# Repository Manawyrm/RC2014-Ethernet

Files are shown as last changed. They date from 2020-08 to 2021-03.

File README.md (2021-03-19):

RC2014 RTL8019 Ethernet card
---------------------

RTL8019 network card  

The design is optimized for automated assembly at [JLCPCB](https://jlcpcb.com/DDE).  

[Schematic](gerbers/RevA/RevA.pdf)  
[Firmware](https://github.com/Manawyrm/RC2014-Ethernet-Firmware)  

Rev. A Errata:   
- Reset polarity is wrong, reset trace needs to be cut and wired to VCC (reset is done in software)
- Interrupt polarity is also wrong, remove R7. (to use interrupts, use an N-channel MOSFET to drive the INT line. Untested!)
- RTL8019 requires an SPI 9346 EEPROM for it's configuration data (for full-duplex ethernet, correct function of the LEDs, proper MAC addresses), which is missing
- RTL8019 footprint is wrong (too small). JLCPCB can still assemble these boards, but it's marked as a manufacturing error.

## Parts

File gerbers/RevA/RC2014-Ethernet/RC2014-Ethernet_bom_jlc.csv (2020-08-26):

Comment | Designator | Footprint | LCSC Part #
1nF | C2,C1,C5,C6 | C_1206_3216Metric | C9196
20p | C3,C4 | C_0402_1005Metric | C1554
100n | C7,C9,C10,C8,C11 | C_0402_1005Metric | C1525
Ferrite_Bead | FB3 | L_0805_2012Metric | C1017
27k | R1 | R_0402_1005Metric | C25771
1M | R2 | R_0402_1005Metric | C26083
10k | R3 | R_0402_1005Metric | C25744
200R | R4,R7 | R_0402_1005Metric | C25087
1k | R5,R6 | R_0402_1005Metric | C11702
13F-39MNL | T1 | SOIC-16W-12_7.5x10.3mm_P1.27mm | C115949
RTL8019AS | U1 | PQFP-100_14x20mm_P0.65mm | C10016
74LS138 | U2 | SOIC-16_3.9x9.9mm_P1.27mm | C5602
20MHz | Y1 | Crystal_SMD_3225-4Pin_3.2x2.5mm | C110936

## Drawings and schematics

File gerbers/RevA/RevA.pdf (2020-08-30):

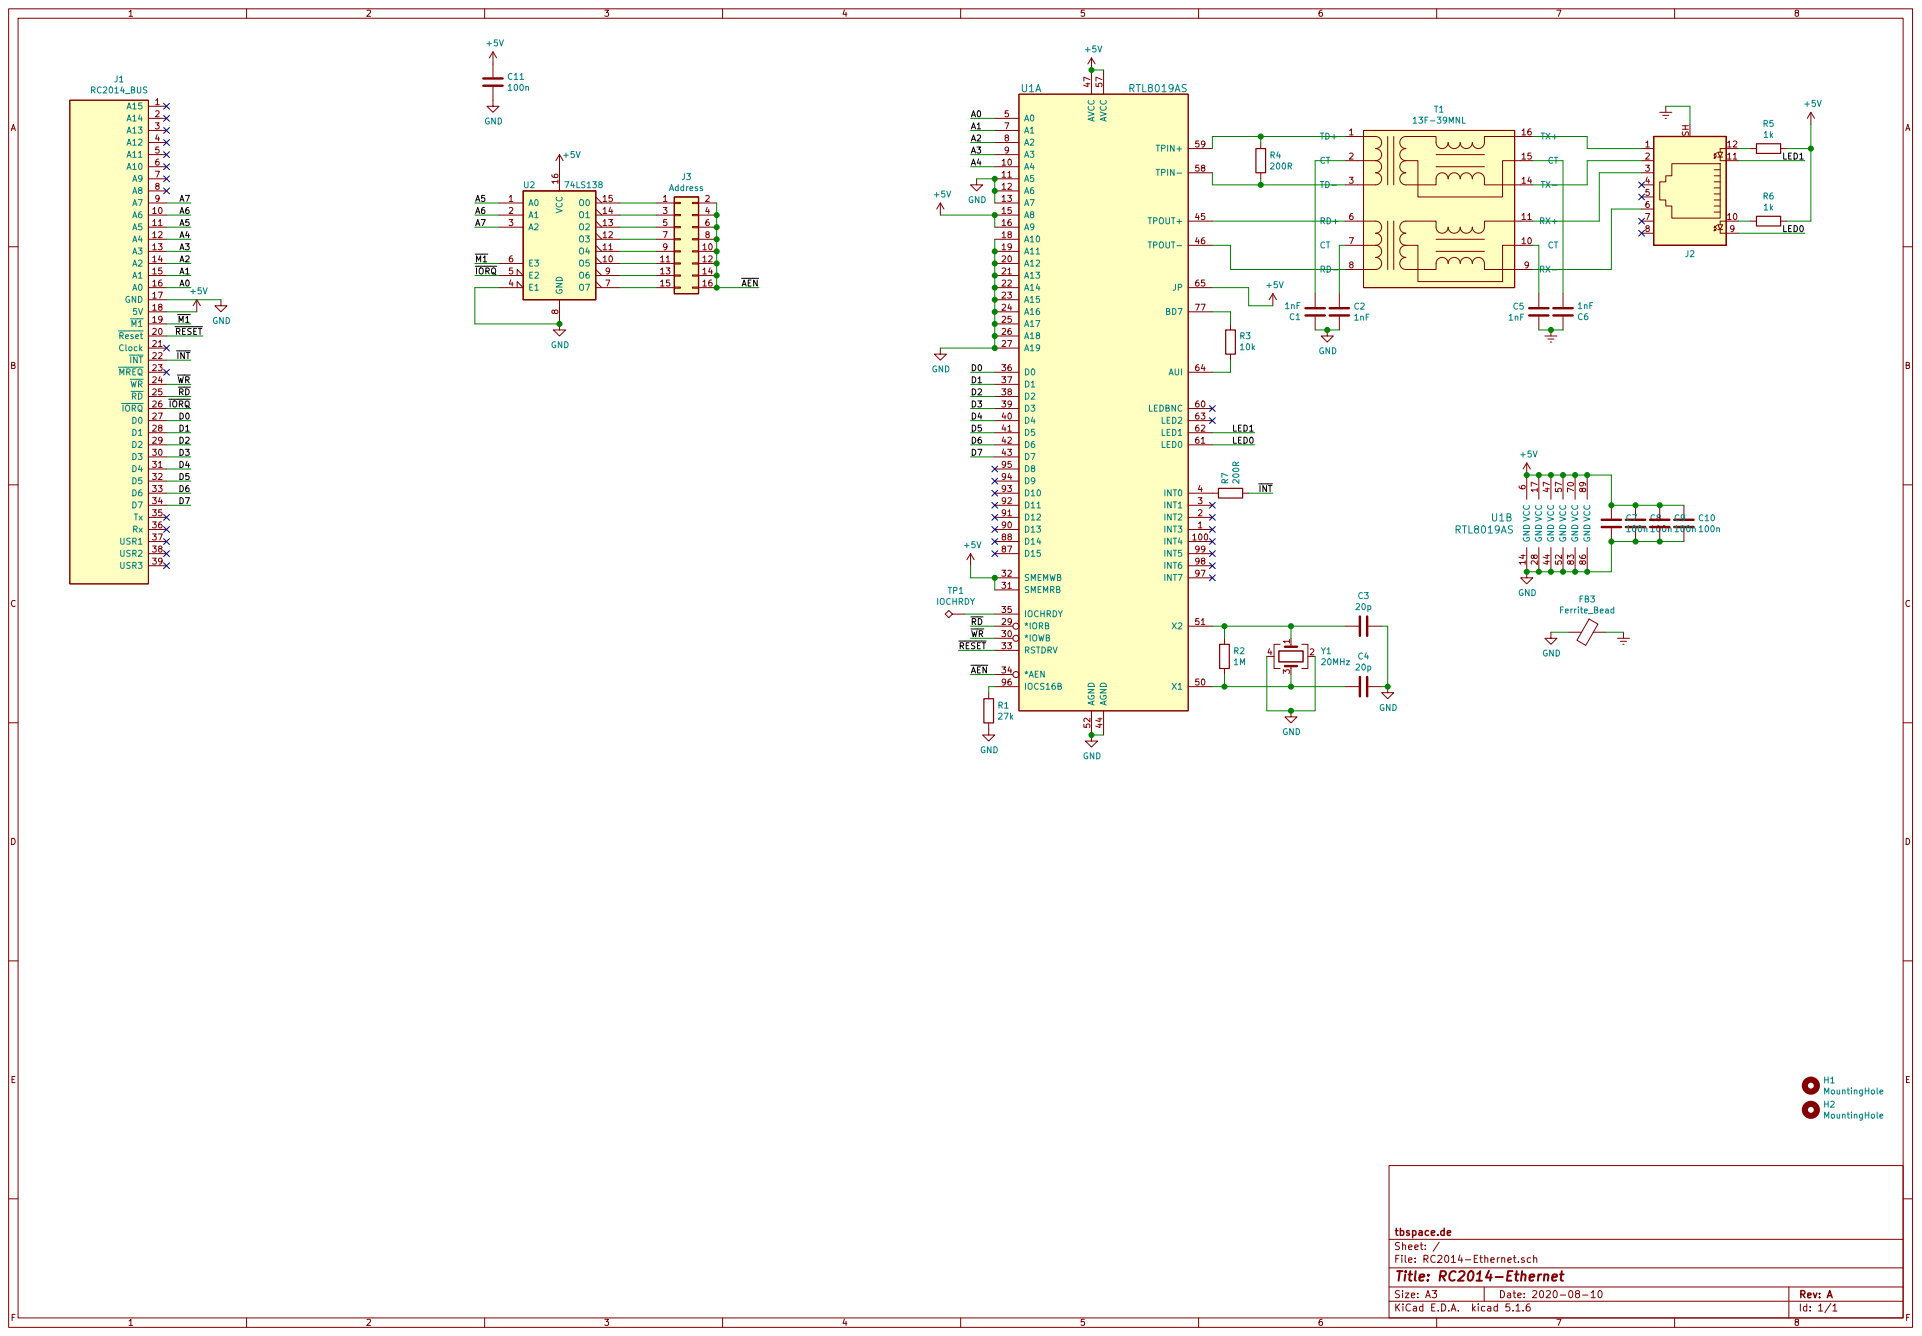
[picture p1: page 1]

11 | 12
13 | 14

Id: 1/1 Title: RC2014-Ethernet File: RC2014-Ethernet.sch Sheet: / tbspace.de

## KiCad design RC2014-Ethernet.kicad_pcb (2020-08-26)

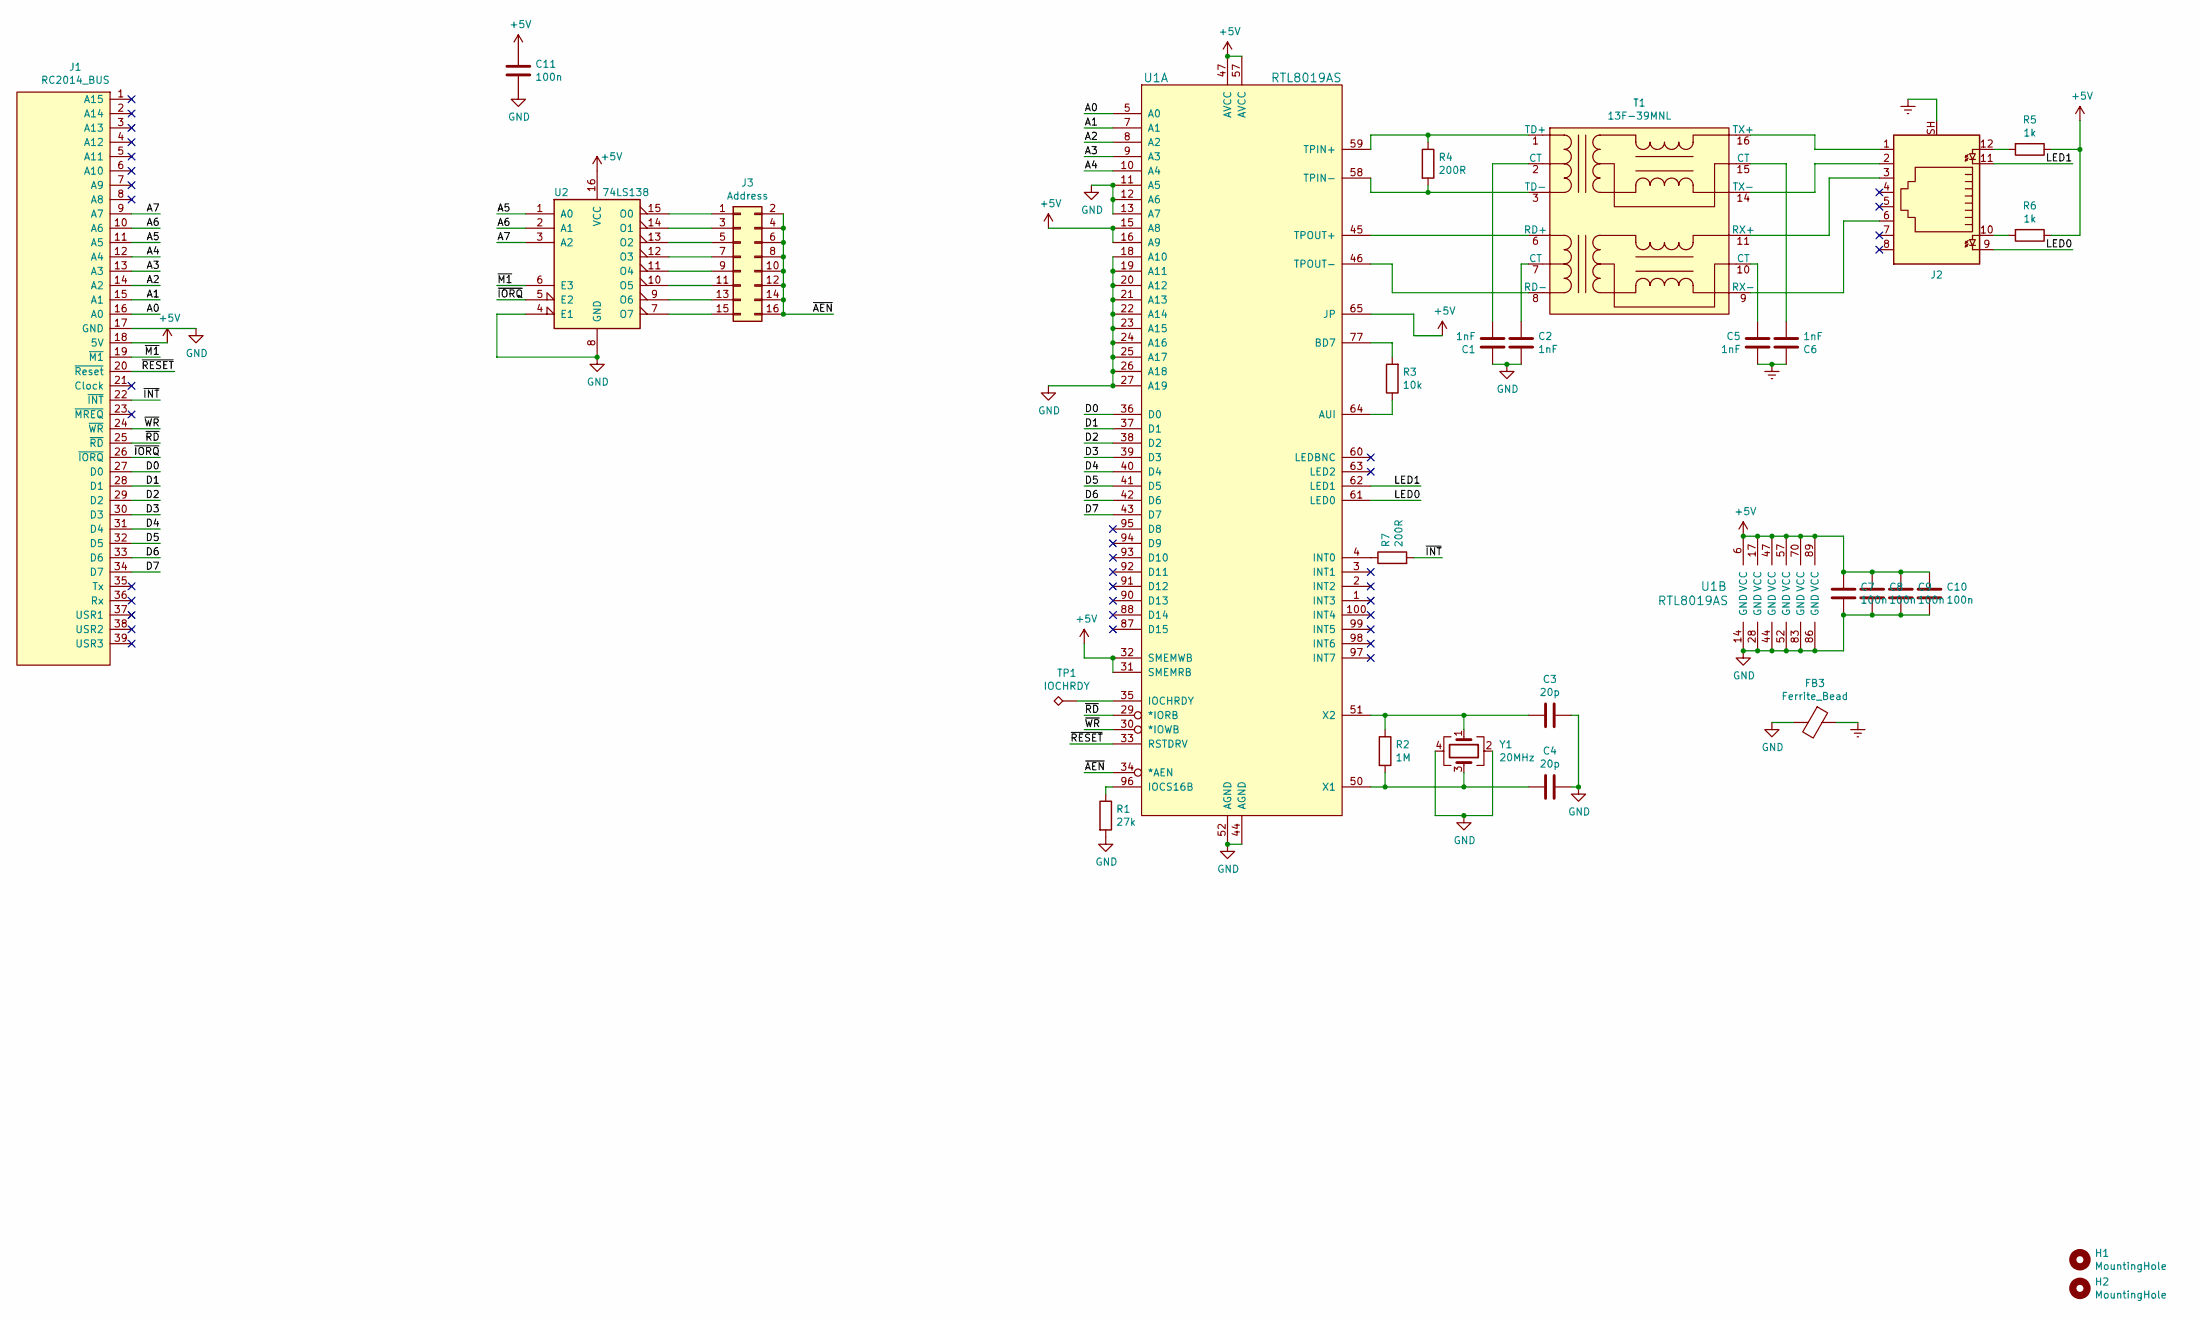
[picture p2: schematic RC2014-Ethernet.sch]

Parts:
C1, C2, C5, C6: 1nF; C_1206_3216Metric; LCSC C9196
C3, C4: 20p; C_0402_1005Metric; LCSC C1554
C7, C8, C9, C10, C11: 100n; C_0402_1005Metric; LCSC C1525
FB3: Ferrite_Bead; L_0805_2012Metric; LCSC C1017
H1, H2: MountingHole; ToolingHole_JLCSMT
J1: RC2014_BUS; PinHeader_1x39_P2.54mm_Vertical
J2: 8P8C_Shielded; 8P8C_yellow_green_Ckmtw_C133529
J3: Address; PinHeader_2x08_P2.54mm_Vertical
R1: 27k; R_0402_1005Metric; LCSC C25771
R2: 1M; R_0402_1005Metric; LCSC C26083
R3: 10k; R_0402_1005Metric; LCSC C25744
R4, R7: 200R; R_0402_1005Metric; LCSC C25087
R5, R6: 1k; R_0402_1005Metric; LCSC C11702
T1: 13F-39MNL; SOIC-16W-12_7.5x10.3mm_P1.27mm; LCSC C115949
TP1: IOCHRDY; TestPoint_Pad_2.5x2.5mm
U1: RTL8019AS; PQFP-100_14x20mm_P0.65mm; LCSC C10016
U2: 74LS138; SOIC-16_3.9x9.9mm_P1.27mm; LCSC C5602
Y1: 20MHz; Crystal_SMD_3225-4Pin_3.2x2.5mm; LCSC C110936

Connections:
+5V: C7.1, C8.1, C9.1, C10.1, C11.1, J1.18 (5V), R5.1, R6.1, U1.6 (VCC), U1.15 (A8), U1.16 (A9), U1.17 (VCC), U1.31 (SMEMRB), U1.32 (SMEMWB), U1.47 (AVCC), U1.57 (AVCC), U1.65 (JP), U1.70 (VCC), U1.89 (VCC), U2.16 (VCC)
/A0: J1.16 (A0), U1.5 (A0)
/A1: J1.15 (A1), U1.7 (A1)
/A2: J1.14 (A2), U1.8 (A2)
/A3: J1.13 (A3), U1.9 (A3)
/A4: J1.12 (A4), U1.10 (A4)
/A5: J1.11 (A5), U2.1 (A0)
/A6: J1.10 (A6), U2.2 (A1)
/A7: J1.9 (A7), U2.3 (A2)
/D0: J1.27 (D0), U1.36 (D0)
/D1: J1.28 (D1), U1.37 (D1)
/D2: J1.29 (D2), U1.38 (D2)
/D3: J1.30 (D3), U1.39 (D3)
/D4: J1.31 (D4), U1.40 (D4)
/D5: J1.32 (D5), U1.41 (D5)
/D6: J1.33 (D6), U1.42 (D6)
/D7: J1.34 (D7), U1.43 (D7)
/LED0: J2.9, U1.61 (LED0)
/LED1: J2.11, U1.62 (LED1)
/~AEN: J3.2, J3.4, J3.6, J3.8, J3.10, J3.12, J3.14, J3.16, U1.34 (*AEN)
/~INT: J1.22 (~INT), R7.2
/~IORQ: J1.26 (~IORQ), U2.5 (E2)
/~M1: J1.19 (~M1), U2.6 (E3)
/~RD: J1.25 (~RD), U1.29 (*IORB)
/~RESET: J1.20 (~Reset), U1.33 (RSTDRV)
/~WR: J1.24 (~WR), U1.30 (*IOWB)
Earth: C5.2, C6.1, FB3.1, J2.SH
GND: C1.1, C2.2, C3.1, C4.1, C7.2, C8.2, C9.2, C10.2, C11.2, FB3.2, J1.17 (GND), R1.2, U1.11 (A5), U1.12 (A6), U1.13 (A7), U1.14 (GND), U1.18 (A10), U1.19 (A11), U1.20 (A12), U1.21 (A13), U1.22 (A14), U1.23 (A15), U1.24 (A16), U1.25 (A17), U1.26 (A18), U1.27 (A19), U1.28 (GND), U1.44 (AGND), U1.52 (AGND), U1.83 (GND), U1.86 (GND), U2.4 (E1), U2.8 (GND), Y1.2, Y1.4
unnamed: C1.2, T1.2 (CT)
unnamed: C2.1, T1.7 (CT)
unnamed: C3.2, R2.1, U1.51 (X2), Y1.1
unnamed: C4.2, R2.2, U1.50 (X1), Y1.3
unnamed: C5.1, T1.10 (CT)
unnamed: C6.2, T1.15 (CT)
unnamed: J2.1, T1.16 (TX+)
unnamed: J2.2, T1.14 (TX-)
unnamed: J2.3, T1.11 (RX+)
unnamed: J2.6, T1.9 (RX-)
unnamed: J2.10, R6.2
unnamed: J2.12, R5.2
unnamed: J3.1, U2.15 (O0)
unnamed: J3.3, U2.14 (O1)
unnamed: J3.5, U2.13 (O2)
unnamed: J3.7, U2.12 (O3)
unnamed: J3.9, U2.11 (O4)
unnamed: J3.11, U2.10 (O5)
unnamed: J3.13, U2.9 (O6)
unnamed: J3.15, U2.7 (O7)
unnamed: R1.1, U1.96 (IOCS16B)
unnamed: R3.1, U1.64 (AUI)
unnamed: R3.2, U1.77 (BD7)
unnamed: R4.1, T1.1 (TD+), U1.59 (TPIN+)
unnamed: R4.2, T1.3 (TD-), U1.58 (TPIN-)
unnamed: R7.1, U1.4 (INT0)
unnamed: T1.6 (RD+), U1.45 (TPOUT+)
unnamed: T1.8 (RD-), U1.46 (TPOUT-)
unnamed: TP1.1, U1.35 (IOCHRDY)

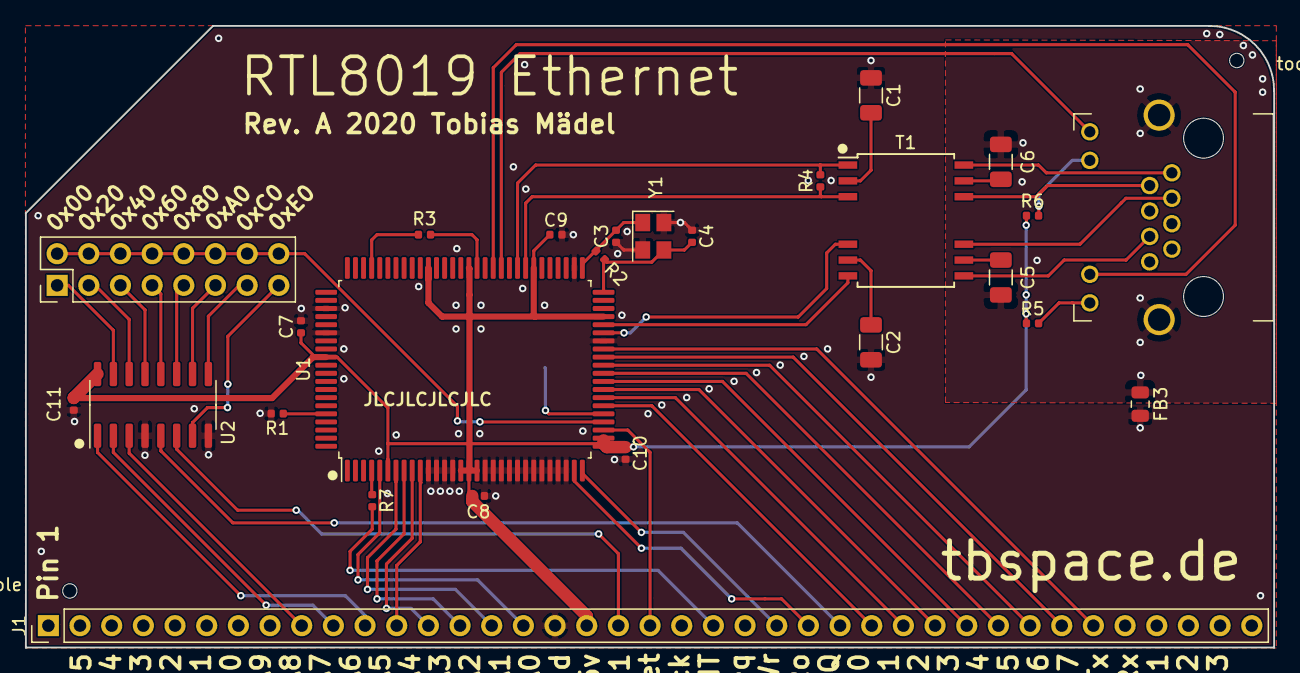
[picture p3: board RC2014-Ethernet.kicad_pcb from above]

Board: 2 copper layers, 100.1 x 49.9 mm, 29 parts (1 on the bottom side), 57 nets.

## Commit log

2020-08-10 Schematic, address layout, modified symbol
    [RC2014-Ethernet.kicad_pcb, RC2014-Ethernet.sch]
2020-08-16 add address decoding and first traces
    [RC2014-Ethernet.kicad_pcb, RC2014-Ethernet.sch]
2020-08-16 Finish layout
    [RC2014-Ethernet.kicad_pcb, RC2014-Ethernet.sch]
2020-08-26 RevA, Tooling holes, via stitching
    [RC2014-Ethernet-B_Cu.gbl, RC2014-Ethernet-B_Mask.gbs, RC2014-Ethernet-B_Paste.gbp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]
2020-08-30 Add readme and schematic pdf
